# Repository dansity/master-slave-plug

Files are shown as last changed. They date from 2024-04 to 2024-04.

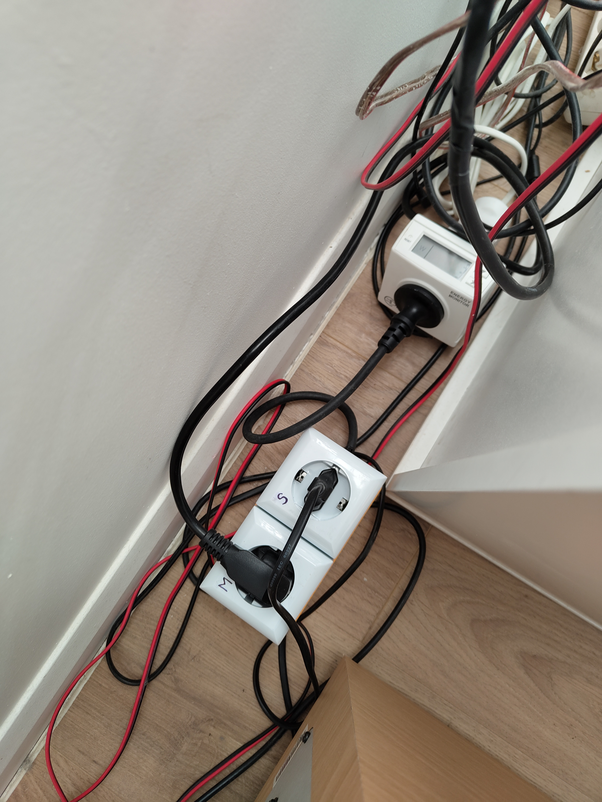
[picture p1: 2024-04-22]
images/IMG_20240420_175650599.jpg

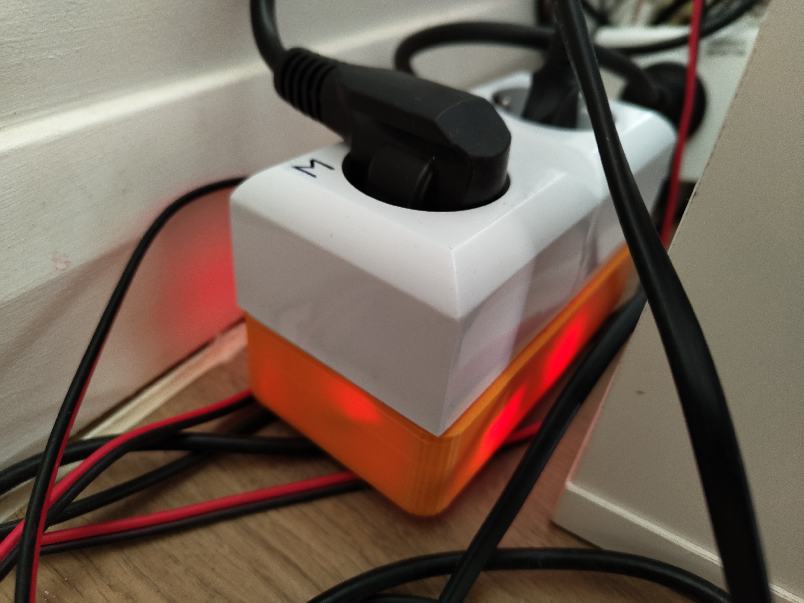
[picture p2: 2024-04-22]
images/IMG_20240422_101913966.jpg

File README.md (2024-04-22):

# master-slave-plug

This is a basic master-slave power plug for mains powered devices. I use it for my hi-fi where I want the amplifier to turn on the subwoofer.

The design does not contain 3d model as you can pick any box you want. I downloaded a parametric box from thingiversre and printed it as is. I prefer drilling holes after the box is done, faster and gives flexibility. So to simply put you can buy any box from an electrical supply shop or print a box for yourself.

Shopping list:
- 2 wall mounted sockets. Don't buy ganged sockets as they are usually connected internally. Buy two individual single sockets.
- Any microcontroller. Project uses 1 digital pin and 1 analog pin which is available on almost any microcontroller. I have used an arduino nano.
- 230V to 5v power supply or if your microcontroller works with 3.3V get a 3.3v power supply.
- Relay module (5v or 3.3V depending on the microcontroller)
- ACS712-20A current sensor module
- Wago connectors, 1x 4wire and 3x 2wire
- 1.5mm2 solid core wire for the sockets - 3 colors
- 0.14mm2 wire for the low voltage part - 3 colors
- M3 bolts and nuts to fix socket to box
- Some insulating tape or shrink tube

Instructions:
Measure the two sockets together and print a box that is the same size. For depth of the box 40mm will be sufficient but if you have a larger PSU you may print it thicker.
Fix the sockets on the box and connect all wiring according to the wiring schematic.

Add the Filters library attached to your Arduino library.
Upload code to the microcontroller. Change pin numbers if needed.
Current sensor will read -0.04A when no load then the rest of the readings under load will be similarly off by a hair. But this is enough for us to switch.

Now it is set to switch above 0.1A load so I can avoid it to turn on with my amplifier's standby. You can change this setting to your liking by modifying line 43:
current_amps > 0.1

### Be very careful with the mains power, make sure inside the box no bare metal remains, use more insulation then less.

Shopping links:
- mini 5v or 3.3v power supply https://t.ly/VjMxn
- Wall mount socket (EU) https://t.ly/i39MG
- 5v relay module https://t.ly/qhUNn
OR
3.3V relay module https://t.ly/DT1ni
- Arduino Nano https://t.ly/nQxX7
- ACS712-20A Current sensor https://t.ly/Mymd4

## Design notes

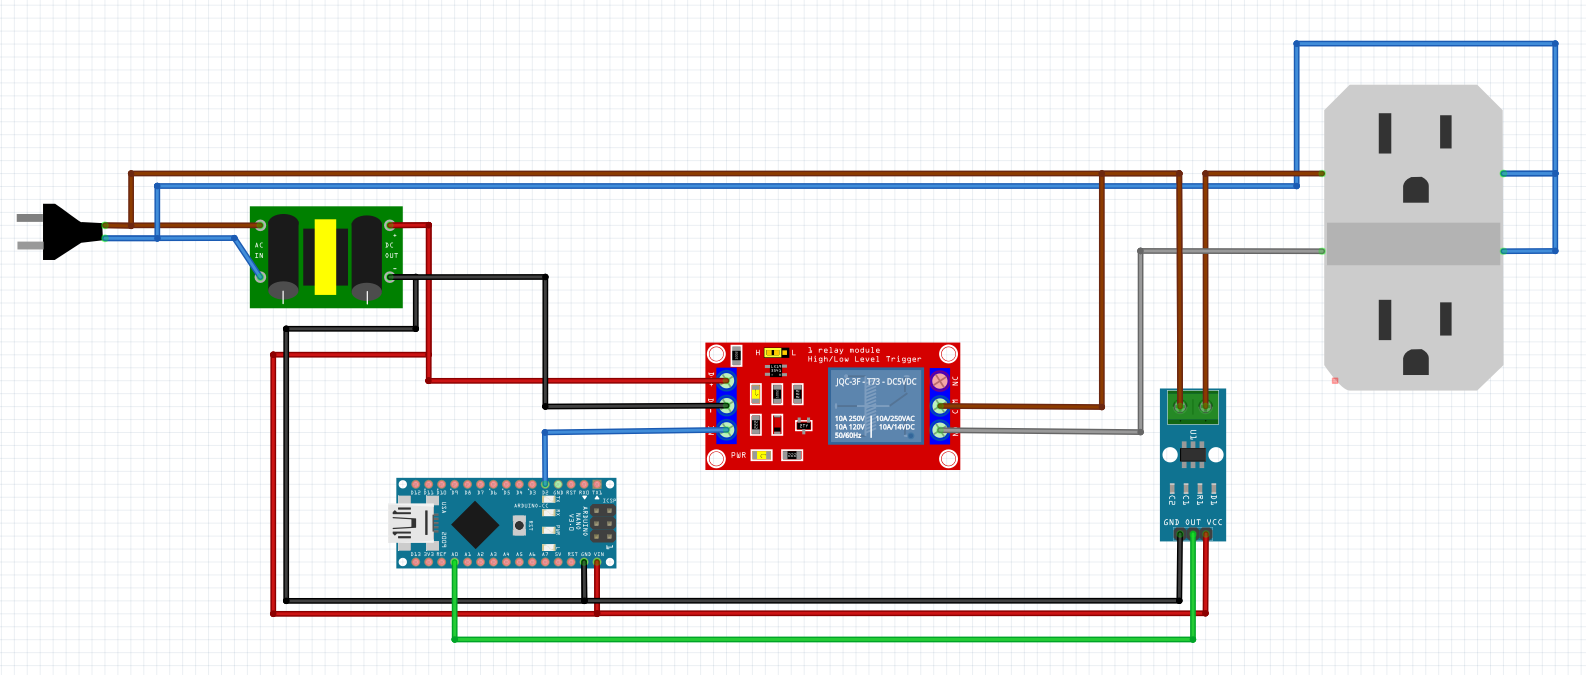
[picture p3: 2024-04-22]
images/schematic.png

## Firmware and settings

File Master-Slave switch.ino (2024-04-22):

#include <Filters.h>
#include <RunningStatistics.h>

float testFrequency = 60;                     // test signal frequency (Hz)
float windowLength = 20.0/testFrequency;     // how long to average the signal, for statistist
int sensorValue = 0;
float intercept = -0.1129; // to be adjusted based on calibration testing
float slope = 0.0405; // to be adjusted based on calibration testing
float current_amps; // estimated actual current in amps
const int relayPin = 2;          // Digital pin for relay module
bool relayState = false; // Keeps track of relay state

unsigned long printPeriod = 1000; // in milliseconds
// Track time in milliseconds since last reading 
unsigned long previousMillis = 0;

void setup() {
  Serial.begin( 57600 );    // start the serial port
    // Initialize the relay pin as an output
  pinMode(relayPin, OUTPUT);
}

void loop() {
  RunningStatistics inputStats;                 // create statistics to look at the raw test signal
  inputStats.setWindowSecs( windowLength );
   
  while( true ) {   
    sensorValue = analogRead(A0);  // read the analog in value:
    inputStats.input(sensorValue);  // log to Stats function
        
    if((unsigned long)(millis() - previousMillis) >= printPeriod) {
      previousMillis = millis();   // update time
      
      // display current values to the screen
      Serial.print( "\n" );
      // output sigma or variation values associated with the inputValue itsel
      Serial.print( "\tsigma: " ); Serial.print( inputStats.sigma() );
      // convert signal sigma value to current in amps
      current_amps = intercept + slope * inputStats.sigma();
      Serial.print( "\tamps: " ); Serial.print( current_amps );
    }
      // Check if current exceeds 0.1A (100mA)
  if (current_amps > 0.1) {
      digitalWrite(relayPin, HIGH);
      relayState = true;
    }
  else {
      digitalWrite(relayPin, LOW);
      relayState = false;
    }
  }
}
